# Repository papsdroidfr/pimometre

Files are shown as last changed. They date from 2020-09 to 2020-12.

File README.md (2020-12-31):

# pimometre

Mini station météo de salon connecté équipée d'un capteur de température et d'humidité pour la température ambiante.
Récupération de prévisions météorologiques via une API Rest. 
Les données sont affichées sur un petit écran LCD de 2 lignes de 16 caractères.

Le tutoriel complet du projet est partagé sur mon site: [pimometre](https://www.papsdroid.fr/post/pimometre)

## prototype de test avec capteur et écran LCD

#### choix matériel

* Raspberry pi Zero WH avec Raspbian os lite et WIFI
* 1 capteur température et humidité: DHT22 (précision T°: 0.5°C, précision humidité: 5%)
* 1 résistance 4,7 k ohms
* 1 écran LCD 16*2 avec backpack I2C à base de PCF8574

Pour configurer le piZero: suivez [ce guide](https://www.papsdroid.fr/post/configurer-pizero)

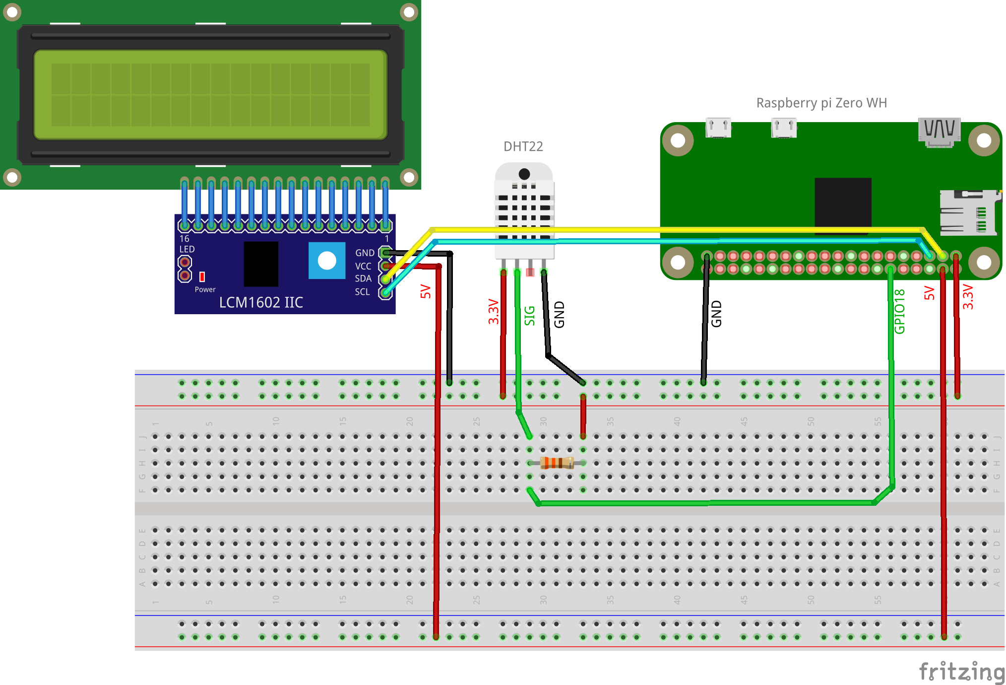
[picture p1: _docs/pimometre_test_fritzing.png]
fritzing_prototype_test


#### test capteur DHT22

Il faut tout d'abord activer l'interface I2C du Raspberry pi avec 
```bach
sudo raspi-config
```
reboot nécessaire.

Pour le capteur DHT22, il faut instaler les dépendances et bilbiothèques circuit-python d'Adafruit en suivant [ce guide](https://circuitpython.readthedocs.io/projects/dht/en/latest/). Pour ce qui me concerne j'ai enchaîné ces commandes:

```bach
sudo pip3 install rpi.GPIO
sudo pip3 install adafruit-blinka
sudo pip3 install adafruit-circuitpython-dht
sudo apt-get install libgpiod2
```

Pour l'afficheur LCD j'ai récupéré la bilbiothèque I2C_LCD_DRIVER.py que je trouve particulièrement bien faite et complète sur [ce site](https://www.circuitbasics.com/raspberry-pi-i2c-lcd-set-up-and-programming/).

Les scripts pythons ci-dessous permettent d'afficher la température et l'humidité ambiante sur le LCD:
* test_LCD_dht22.py
* I2C_LCD_DRIVER.py

Les deux fichiers sont à déposer dans un répertoire /home/pi/pimometre/tests/ du raspberry pi zero.

usage: 
```bach
python3 pimometre/tests/test_LCD_dht22.py
```

#### test API météo

Pour récupérer les prévisions météorologiques locales, il faut d'abord créer un token "standard" sur https://api.meteo-concept.com/

Récupérer votre token, et stockez le dans un fichier texte "tokenAPI.txt", à déposer dans le dossier /home/pimometre/tests, ainsi que le programme python test_meteo_api.py à récupérer parmi les sources.

usage:
```python
cd pimometre/tests
python3 test_meteo_api.py [CP] 
```
en remplaçant [CP] par un code postal dont vous souhaitez les prévisions météo
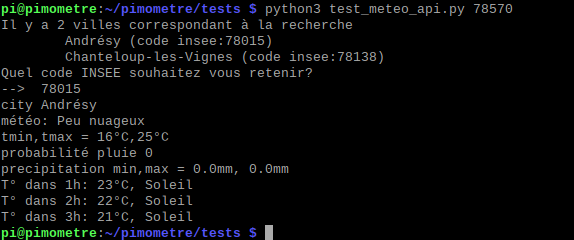
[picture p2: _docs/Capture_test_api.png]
test_api


Pour un même code postal il peut y avoir plusieurs villes: identifiez le code INSEE de la ville pour laquelle vous souhaitez avoir les prévisions météo: ce code sera utilisé pour la suite du projet.

#### première version test du projet: météo interne (capteur) et externe (api).

le programme **pimometre_v1.1.py** dans le répertoire **/tests** permet d'afficher la météo interne capté par le capteur DHT22 (T° et taux d'humidité), ainsi que la température et taux d'humidité exterieure fournie par l'API.

usage: 
```python
cd pimometre/tests
python3 pimometre_v1.1.py [INSEE]
```

remplacer [INSEE] par le code INSEE de votre ville (récupérée via le programme **test_meteo_api.py**) 
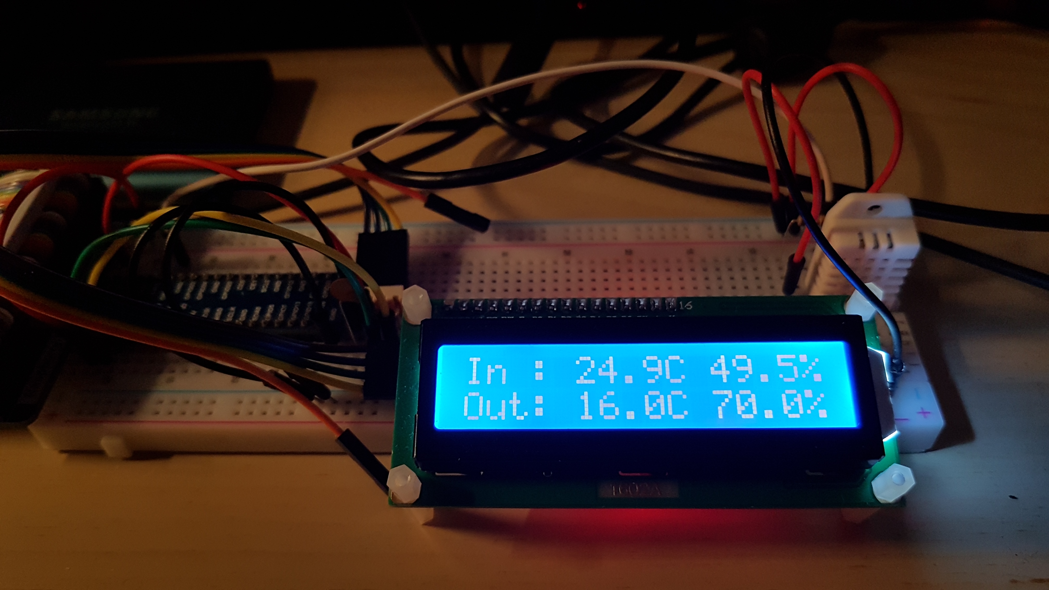
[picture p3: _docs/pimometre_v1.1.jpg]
test_v1.1


Pour pouvoir afficher des informations asynchrones sur un écran (LCD 16*2 en l'occurence), la meilleure solution est de confier la lecture des capteurs à des Threads indépendants. L'application principale consiste à afficher en boucle infinie avec un temps de repos pour ne pas saturer les processeurs ce que les Threads de lecture ont enregistrés la dernière fois qu'ils ont capté quelquechose. Grâce aux Threads On peut ainsi afficher de manière régulière des informations captées par des capteurs qui ne sont absolument pas synchronisés.

Ce programme (orienté objet) contient 3 classes pour gérer l'application:
* Classe **Application**, avec sa boucle principale **loop()** qui affiche en boucle infinie toutes les 2 secondes sur l'écran LCD les lectures faites par le DHT22 et l'appel à l'API météo.
* Classe **DHT22**: capteur interne de T° et humidité. Ce capteur est capricieux et provoque souvent des erreurs de lecture qu'il faut ignorer, et il est conseillé d'attendre au minimum 2 secondes avant de retenter une lecture: un Thread qui lit et enregistre en boucle infinie ce capteur toutes les 2 secondes est particulièrement bien adapté.
* Classe **Meteo**: Thread de lecture de prévision météo via l'api https://api.meteo-concept.com. Ce thread va interroger l'API toutes les 15 mn (60*15 secondes) pour enregistrer la T° et le taux d'humidité de la ville correspondant au code [INSEE] fourni en paramètre lors de l'appel au programme. Attention l'appel à cette API nécessite que vous aillez au préalable **déclaré votre propre token dans le fichier de configuration tokenAPI.txt**

Une seconde version du programme **pimometre_v1.2.py** va permettre de faire défiler plusieurs informations sur la ligne des prévisions météos: température et humidité extérieure, puis vitesse du vent et probabilité de pluie, et enfin le buletin météo qui apparaît en scrolling de la droite vers la gauche.

## projet complet

#### matériel nécessaire

* 1 Raspberry pi Zero WH avec Raspbian os lite et WIFI
* 1 capteur température et humidité: DHT22 (précision T°: 0.5°C, précision humidité: 5%)
* 1 résistance 4,7 k ohms
* 1 écran LCD 16*2 avec backpack I2C à base de PCF8574
* 2 condensateurs céramiques 100nf
* 4 résistances 10 k ohms
* 2 boutons poussoirs 6mm 4 pattes
* 1 jack Barrel DC
* 1 alimentation 5v 2A jack DC
* 1 barette femelle 2*20pin pas 2,54mm pour raspberry pi
* 1 connecteur 4 pin header coudé mâle 2,54mm (pour brancher le LCD)
* 1 connecteur 3 pin header coudé mâle 2,54mm (popur brancher le capteur DHT22)
* des câbles dupond souples femelle/femelle pour racorder le LCD et le DHT22 à la carte
* un jeux d'entretoises nylons M2.5 pour fixer le LCD et surélever le PCB.

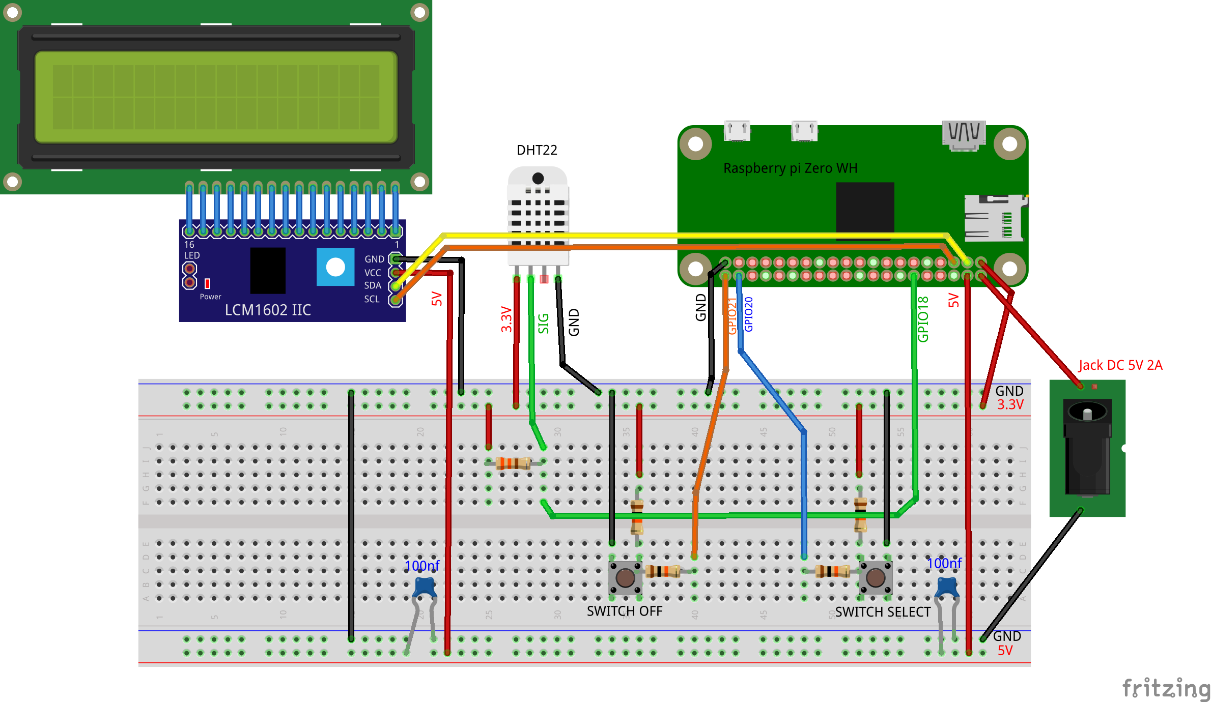
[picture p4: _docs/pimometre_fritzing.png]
fritzing_prototype


#### circuit imprimé

utilisez le fichier zippé **GERBER_pimometre.zip** pour commander le circuit imprimé auprès de n'importe quel fabriquant de PCB.
Vous pourrez y souder tous les composants: les indications claires sont sérigraphiées.
Le raspberry pi se loge par dessous le PCB.
Le LCD et le DHT22 sont connectés à la carte avec des câbles souple femelle/femelle qui se retrouvent entre le circuit imprimé et l'afficheur LCD. 
Il est important de maintenir le capteur DHT22 éloigné du système, pour ne pas que la chaleur dégagée par le raspberry ne perturbe les mesures.

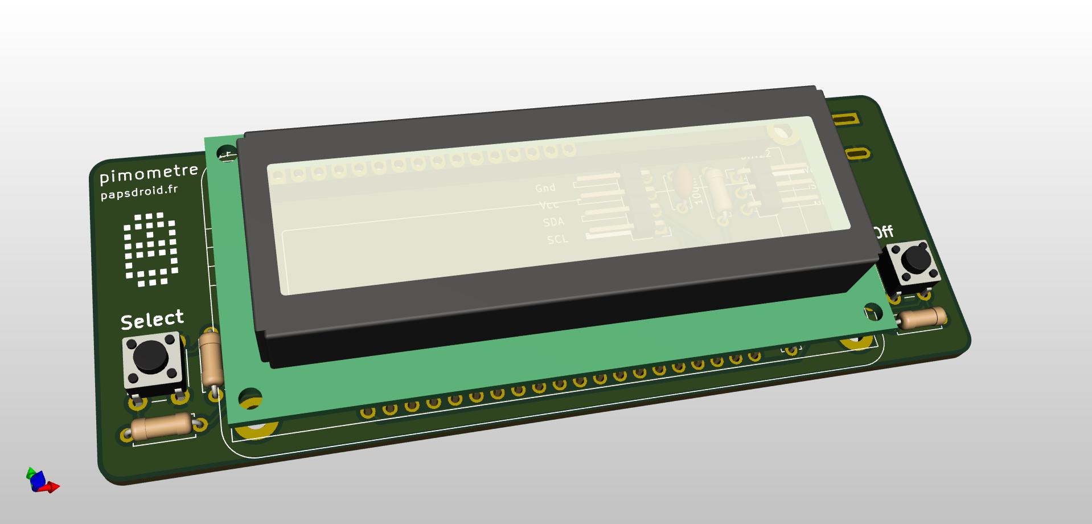
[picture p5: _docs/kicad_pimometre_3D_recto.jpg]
PCB_3D


#### installation du programme python

Dans le répertoire **/home/pi/pimometre** déposer les fichiers **tokenAPI.txt**,  **I2C_LCD_DRIVER.py**, et **pymometre.py** 
Il faut enregistrer son propre token déclaré préalablement dans https://api.meteo-concept.com/ dans le fichier tokenAPI.txt
Installez bien toutes les dépendances comme expliqué dans la partie tests.

Testez d'abord le programme en vous connectant en SSH au piZero:
 
```python
python3 pimometre/pimometre.py [INSEE]
```

remplacer [INSEE] par le code INSEE de votre ville (à ne pas confondre avec le CODE POSTAL ...)

Des messages seront affichés s'il y a des problèmes.

Le script est prévu pour interroger toutes les 5mn l'API météo (cequi génère au maximum 288 appels d'API par jour), et toutes les 10 secondes le capteur DHT22. 
* la première ligne concerne la température et humidité ambiante captée par le DHT22
* la seconde ligne concerne les prévisions météo extérieures via l'API: un premier écran avec la température et l'humidité pendant 2 secondes, puis un second écran avec la vitesse du vent et la probabilité de pluie (2s), un troisième écran avec le bulletin météo en scrolling. La légende à gauche de l'écran indique l'heure de la prévision et une petite icône représentative de ce qui est affiché (thermomètre / soleil / pluie / 5 niveaux de pluie)
* Un appui sur le bouton **Select** va afficher les prévisions météo dans 3h, puis 6h, 9h et retour à l'heure courante
* un appui sur le bouton **Off** va éteindre le système. Pour le redémarrer: il faut enlever et rebrancher le +5v.

#### automatisation au démarrage

Pour que le programme démarre tout seul au démarrage du raspberry pi, il faut ajouter une commande dans la crontable:

ouvrir la crontab en édition
```bach
sudo nano /etc/crontab -e
```

ajouter ces deux lignes à la fin, avant le #:

```python
@reboot pi python3 -u 'pimometre/pimometre.py' [INSEE] > 'pimometre/pimometre.log' 2>&1 &
@daily reboot
```
pensez à remplacer [INSEE] par le code INSEE de votre ville (à ne pas confondre avec le code postal ...)

tappez CTRL-O pour sauvegarder les changements, puis CTRL-X pour quitter

* La première commande indique qu'au démarrage du pizero (@reboot) le user pi doit éxécuter la commande python3 -u .... et rediriger toutes les sorties vers le fichier pimometre/pimometre.log. **Ne pas oublier le & final** qui signifie d'éxécuter la commande en tâche de fond.
* La seconde commande @daily reboot porte bien son nom: elle provoque un reboot automatique du pizero tous les jours (à minuit): quand un système tourne h24 7J/7 avec des logs qui se remplissent, il est conseillé de faire un reboot de temps en temps.Dasn le cas du pimometre la log est assez "verbeuse" donc vaut mieux rebooter toutes les nuit. 

Vous pouvez éteindre le pizero (**sudo poweroff** en SSH), le débrancher quand la lumière verte est éteinte puis le rebrancher.

Lorsqu'il démarre,le programme se lance au bout de quelques instants: **il est normal que la seconde ligne du LCD indique qu'il y a un problème WIFI**: en effet le démarrage des services WIFI est plus lent que l'exécution de la crontable et il faut donc patienter 5mn pour que la deuxième tentative d'appel API (toutes les 5mn) se fasse avec le WIFI activé. Normalement au bout de 5mn le wifi est activé et les prévisions météo de l'heure en cours s'affichent.

Vous pouvez aussi vous connecter en SSH au piZero, et consulter le contenu du fichier de logs dans /home/pi/pimometre/pimometre.log

Le script python est prévu pour gérer les coupures WIFI (par exemple chez moi je coupe le WIFI toutes les nuits de 23h à 07h): les prévisions météos vont alors afficher **"pb cnx API"** et reprendront toutes seules dès que le WIFI est réactivé (à 5mn près).

## Boîtier imprimé 3D

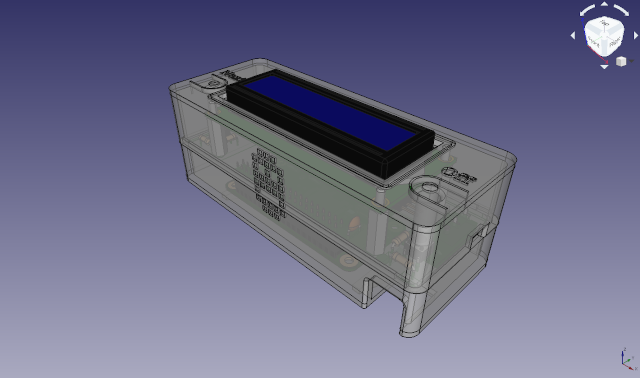
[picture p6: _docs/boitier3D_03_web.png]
pimometre


Un boîtier peut être imprimé en PLA avec une imprimante 3D: télechargez les fichier stl dans le dossier **impression3D** du projet. Ce boîtier peut être imprimé en **0.2mm** (toutes les côtes sont prévues pour) avec les supports uniquement nécessaires pour la coque basse (pour pouvoir imprimer l'ouverture du branchement Jack 5v). Je conseille de cocher l'option **"amélioration de la surface d'adhésion"** car sinon les bords ont tendance à se décoller un peu, ce qui rend la structure du boîtier légèrement bombée et rend difficile (voire impossible) sa fermeture.

Le boîtier peut se poser à plat horizontalement (LCD vers le haut), ou bien inclié à 20° (avec 2 pieds optionnels), ou encore à plat à 90° vissé sur un mur. Il se compose de 3 éléments:
* **coque_basse.stl**: partie basse de la coque dans laquelle se loge la carte. Il faut bien la positionner à raz-bord, elle repose sur les petits rebords. Il faut fixer le LCD avec des petites entretoise nylon M2.5 de **15mm**.
* **coque_haute.stl**: partie haute du boîtier, avec les réhausses de boutons poussoir intégrés. 
* **pied.stl** : à imprimer 2 fois. Ils sont optionnels et ne servent que si vous souhaitez poser le pimomètre incliné à 20°

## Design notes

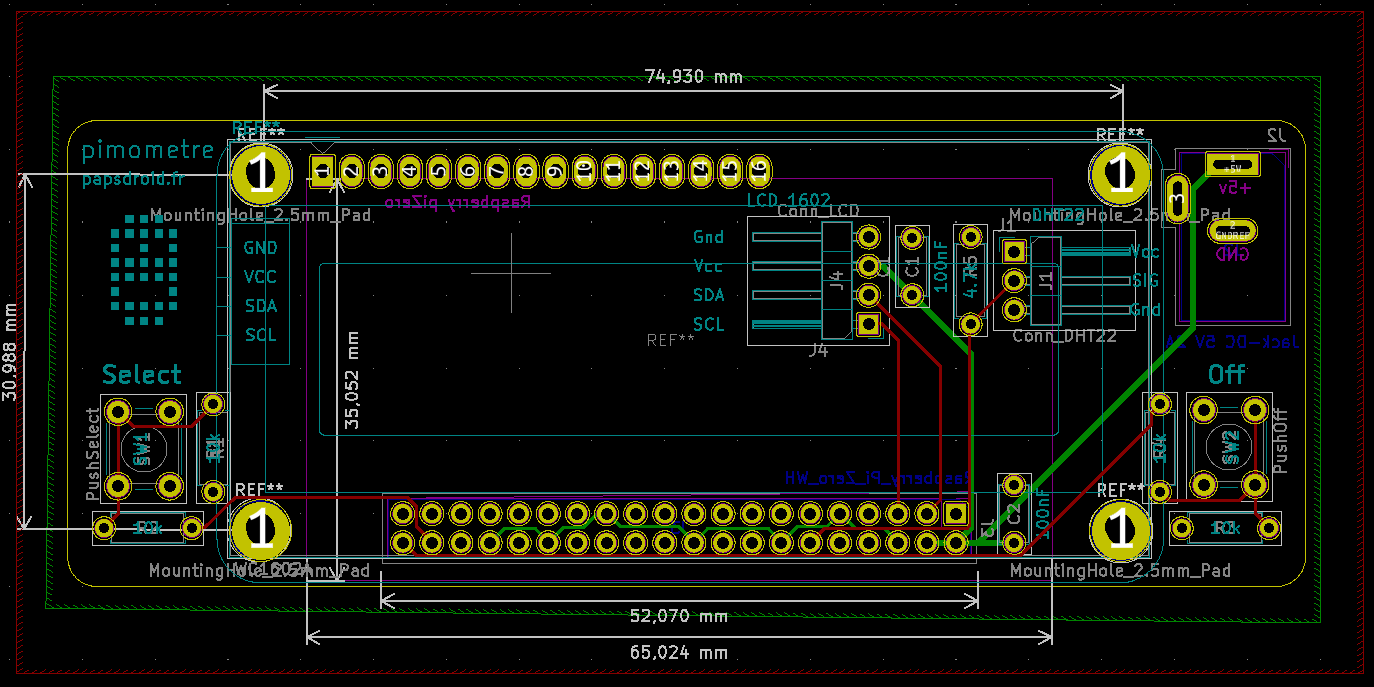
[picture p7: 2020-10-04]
_docs/kicad_pcb.png

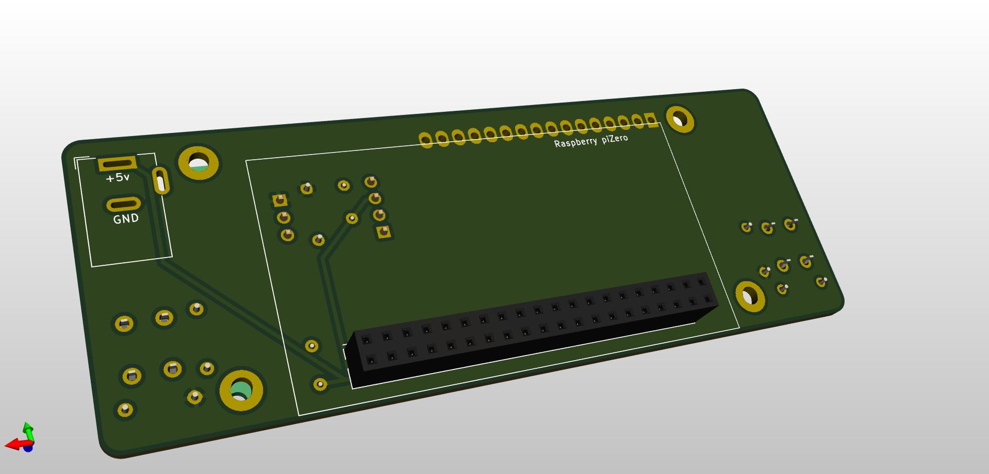
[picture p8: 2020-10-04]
_docs/kicad_pimometre_3D_verso.jpg

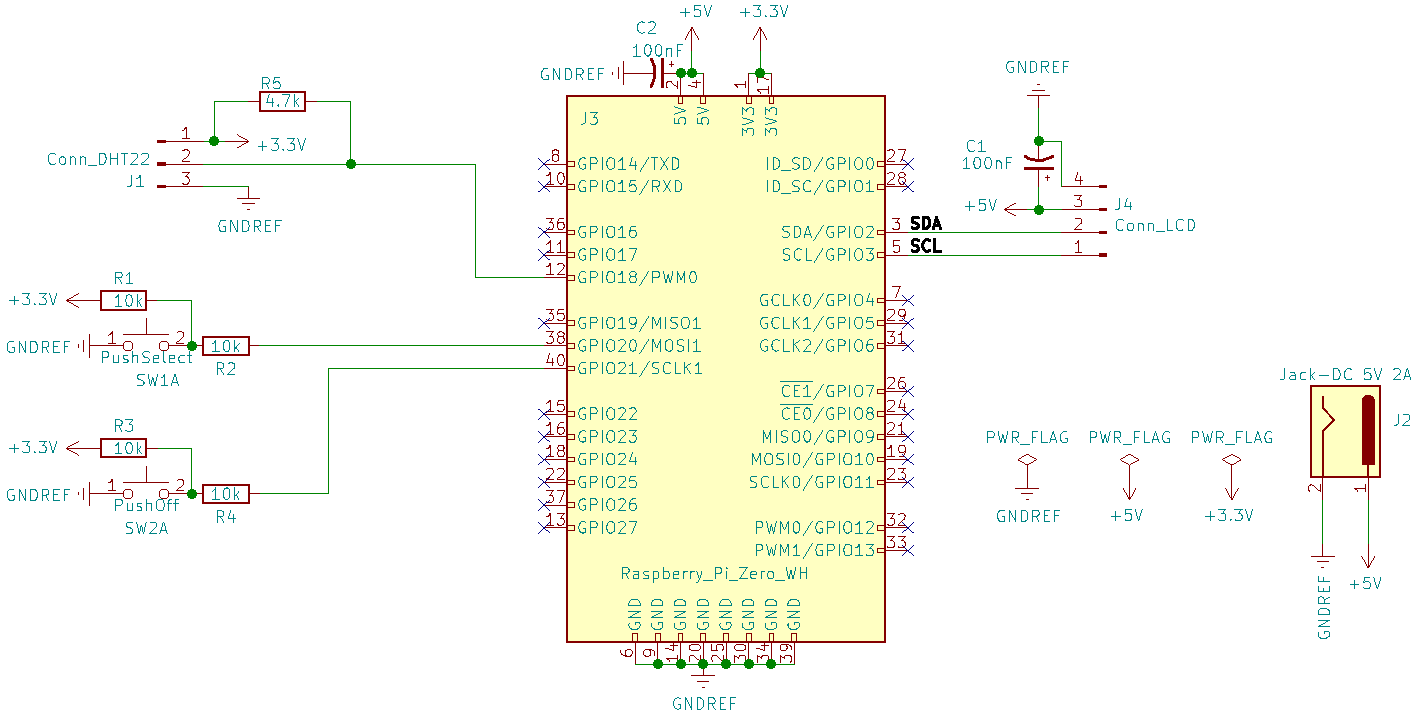
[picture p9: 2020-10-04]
_docs/Kicad_schema.png

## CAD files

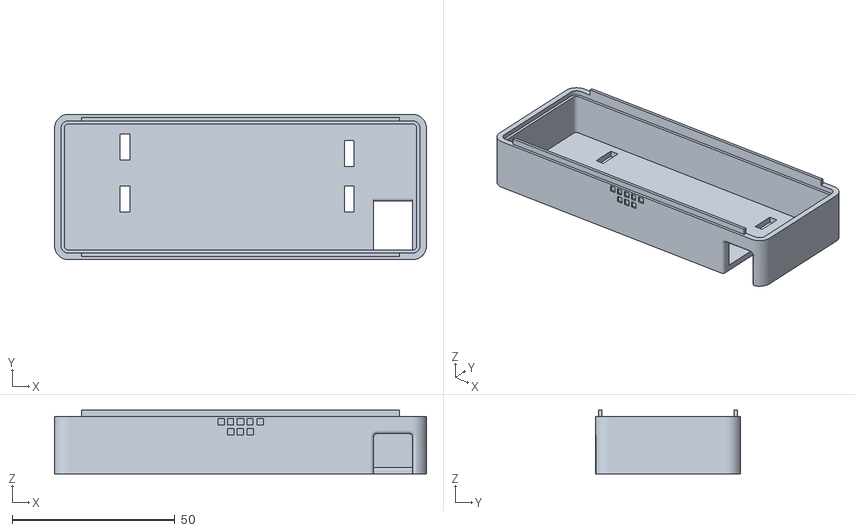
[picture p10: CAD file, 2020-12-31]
impression3D/coque_basse.stl
114.4 x 44.7 x 19.6

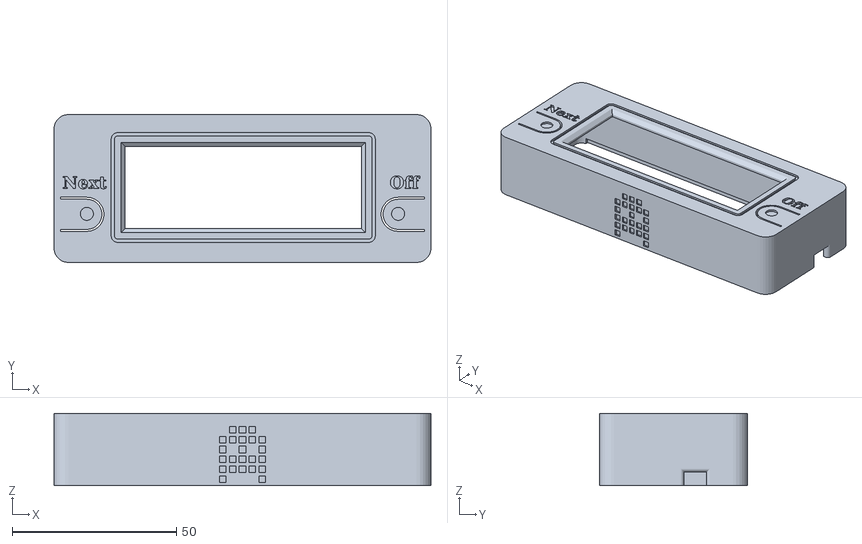
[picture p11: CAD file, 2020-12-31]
impression3D/coque_haute.stl
114.8 x 45.0 x 22.0

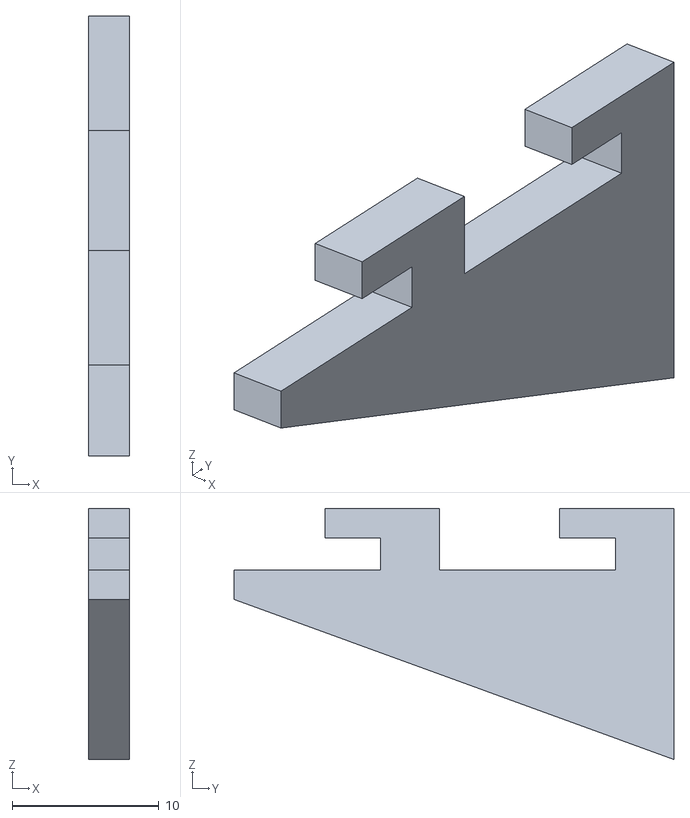
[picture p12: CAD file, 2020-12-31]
impression3D/pied.stl
2.80 x 30.0 x 17.1

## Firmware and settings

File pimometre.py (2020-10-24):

#!/usr/bin/env python3
# -*- coding: utf-8 -*-
########################################################################
# Filename    : pimometre.py
# Description : station météo de salon avec prévision
# auther      : papsdroid.fr
# creation    : 2020/09/20
# modification: 2020/10/24
########################################################################

import RPi.GPIO as GPIO
import time, board,os, adafruit_dht,threading,  I2C_LCD_DRIVER
from datetime import datetime
from contextlib import closing
from urllib.request import urlopen
from urllib.error import URLError
import json, sys, unicodedata


class DHT22(threading.Thread):
    """ classe capteur de t° et humidité DHT22"""
    def __init__(self):
        """ constructeur """
        threading.Thread.__init__(self)  # appel au constructeur de la classe mère Thread
        print("Init capteur DHT22")
        self.dhtDevice = adafruit_dht.DHT22(board.D18) # catpeur T°  humidity DHT22
        self.delay = 10                  # delay in s before reading a new mesure
        self.temperature_c = None
        self.humidity = None
        self.readOk   = False            # True: lecture capteur ok
        self.start()                     # start thread

    def run(self):
        """ exécution thread: lit T° et humidité du capteur DHT22 toutes les sefl.delay secondes
            valeurs stockées dans self.temperature_c et self.humidity
        """
        self.etat = True
        while self.etat:
            try:
                self.temperature_c = self.dhtDevice.temperature
                self.humidity = self.dhtDevice.humidity
                self.readOk = True
            except :
                self.readOk = False
                print(datetime.now(),' DHT22 read Error')
            time.sleep(self.delay) #wait at least 2s before reading a new mesure
        self.off()  # free dht22 device

    def off(self):
        """ arrêt thread de lecture T° DHT22 """
        print("DHT22 exit")
        self.dhtDevice.exit()

class Meteo(threading.Thread):
    """ recup données API meto https://api.meteo-concept.com/ 
        thread de prevision météo mis à jour toutes les self.delay secondes 
    """
    def __init__(self, insee=None):
        """ constructeur """
        threading.Thread.__init__(self)  # appel au constructeur de la classe mère Thread
        self.delay = 60*5                # délais attente avant nouvelle interrogation API
        self.delay_retry = 5             # délais retentative appel API en cas de pb (exple WIFI KO)
        self.insee = insee               # code INSEE de la ville pour les prévisions
        self.forecast = None             # prévisions météo (API)
        self.apiOK = False               # passe à True si thread démarré et réponse API OK
        #-- get token from tokenAPI.txt file
        try:
            with open('tokenAPI.txt','r') as f:
                self.mytoken= f.read().strip('\n')
                print('token="' + self.mytoken + '"')
        except:
            print('Créer un fichier tokenAPI.txt avec le token en 1ere ligne')
            self.mytoken = None

        #--dic weather code
        self.WEATHER = {
            0: "Soleil",
            1: "Peu nuageux",
            2: "Ciel voilé",
            3: "Nuageux",
            4: "Très nuageux",
            5: "Couvert",
            6: "Brouillard",
            7: "Brouillard givrant",
            10: "Pluie faible",
            11: "Pluie modérée",
            12: "Pluie forte",
            13: "Pluie faible verglaçante",
            14: "Pluie modérée verglaçante",
            15: "Pluie forte verglaçante",
            16: "Bruine",
            20: "Neige faible",
            21: "Neige modérée",
            22: "Neige forte",
            30: "Pluie et neige mêlées faibles",
            31: "Pluie et neige mêlées modérées",
            32: "Pluie et neige mêlées fortes",
            40: "Averses de pluie locales et faibles",
            41: "Averses de pluie locales",
            42: "Averses locales et fortes",
            43: "Averses de pluie faibles",
            44: "Averses de pluie",
            45: "Averses de pluie fortes",
            46: "Averses de pluie faibles et fréquentes",
            47: "Averses de pluie fréquentes",
            48: "Averses de pluie fortes et fréquentes",
            60: "Averses de neige localisées et faibles",
            61: "Averses de neige localisées",
            62: "Averses de neige localisées et fortes",
            63: "Averses de neige faibles",
            64: "Averses de neige",
            65: "Averses de neige fortes",
            66: "Averses de neige faibles et fréquentes",
            67: "Averses de neige fréquentes",
            68: "Averses de neige fortes et fréquentes",
            70: "Averses de pluie et neige mêlées localisées et faibles",
            71: "Averses de pluie et neige mêlées localisées",
            72: "Averses de pluie et neige mêlées localisées et fortes",
            73: "Averses de pluie et neige mêlées faibles",
            74: "Averses de pluie et neige mêlées",
            75: "Averses de pluie et neige mêlées fortes",
            76: "Averses de pluie et neige mêlées faibles et nombreuses",
            77: "Averses de pluie et neige mêlées fréquentes",
            78: "Averses de pluie et neige mêlées fortes et fréquentes",
            100: "Orages faibles et locaux",
            101: "Orages locaux",
            102: "Orages fort et locaux",
            103: "Orages faibles",
            104: "Orages",
            105: "Orages forts",
            106: "Orages faibles et fréquents",
            107: "Orages fréquents",
            108: "Orages forts et fréquents",
            120: "Orages faibles et locaux de neige ou grésil",
            121: "Orages locaux de neige ou grésil",
            122: "Orages locaux de neige ou grésil",
            123: "Orages faibles de neige ou grésil",
            124: "Orages de neige ou grésil",
            125: "Orages de neige ou grésil",
            126: "Orages faibles et fréquents de neige ou grésil",
            127: "Orages fréquents de neige ou grésil",
            128: "Orages fréquents de neige ou grésil",
            130: "Orages faibles et locaux de pluie et neige mêlées ou grésil",
            131: "Orages locaux de pluie et neige mêlées ou grésil",
            132: "Orages fort et locaux de pluie et neige mêlées ou grésil",
            133: "Orages faibles de pluie et neige mêlées ou grésil",
            134: "Orages de pluie et neige mêlées ou grésil",
            135: "Orages forts de pluie et neige mêlées ou grésil",
            136: "Orages faibles et fréquents de pluie et neige mêlées ou grésil",
            137: "Orages fréquents de pluie et neige mêlées ou grésil",
            138: "Orages forts et fréquents de pluie et neige mêlées ou grésil",
            140: "Pluies orageuses",
            141: "Pluie et neige mêlées à caractère orageux",
            142: "Neige à caractère orageux",
            210: "Pluie faible intermittente",
            211: "Pluie modérée intermittente",
            212: "Pluie forte intermittente",
            220: "Neige faible intermittente",
            221: "Neige modérée intermittente",
            222: "Neige forte intermittente",
            230: "Pluie et neige mêlées",
            231: "Pluie et neige mêlées",
            232: "Pluie et neige mêlées",
            235: "Averses de grêle",
            }

        self.URLAPI   = 'https://api.meteo-concept.com/api'
        self.GETHOURS = '/forecast/nextHours'
        self.HOURLY   = '&hourly=true' #GET forecast every  hour
        if (self.mytoken is not None and self.insee is not None):
            self.TOKEN  = '?token='+self.mytoken
            self.SEARCH = '&insee='+self.insee
            self.start() # start thread

    def run(self):
        """ thread start """
        self.etat = True
        while self.etat:
            try:
                with closing(urlopen(self.URLAPI+self.GETHOURS+self.TOKEN+self.HOURLY+self.SEARCH)) as f:
                    decoded = json.loads(f.read())
                    self.forecast = decoded['forecast']
                    self.city = decoded['city']['name']
                    print('{}: mise à jour prévisions météo de {} à {} (nb:{}) {}'.format(datetime.now(),self.forecast[0]['datetime'],
                               self.city, len(self.forecast), self.WEATHER[self.forecast[0]['weather']]))
                    self.apiOK = True
                    time.sleep(self.delay)
            except URLError as error: # HTTPError(req.full_url, code, msg, hdrs, fp)
                if not(self.apiOK) or self.forecast is not None:
                    print(datetime.now(),':pb connexion API, vérifier le token ou la connexion WIFI:',error)
                    self.forecast = None
                time.sleep(self.delay_retry)  # nouvelle tentative toute les self.delay_retry secondes

class LCD:
    """ classe gestion du LCD """
    def __init__(self):
        """ constructeur """
        self.lcd =  I2C_LCD_DRIVER.lcd()        # LCD 16*2
        self.lcd.backlight(1)                   # turn LCD backligth on
        fontdata = [ [0b00100,0b01010,0b01010,0b01010,0b11011,0b10111,0b11111,0b01110], #0 = thermometre
                     [0b00000,0b00100,0b11110,0b11111,0b01010,0b01001,0b00100,0b00000], #1 = clouds rain
                     [0b10101,0b01110,0b10001,0b10001,0b10001,0b01110,0b10101,0b00000], #2 = sun
                     [0b00000,0b01110,0b10001,0b10001,0b10001,0b11111,0b11111,0b00000], #3 level     [0-25[   %
                     [0b00000,0b01110,0b10001,0b10001,0b11111,0b11111,0b11111,0b0000] , #4 level [25-50[  %
                     [0b00000,0b01110,0b10001,0b11111,0b11111,0b11111,0b11111,0b00000], #5 level [50-75[  %
                     [0b00000,0b01110,0b11101,0b11111,0b11111,0b11111,0b11111,0b00000], #6 level [75-100[ %
                     [0b00000,0b01110,0b11111,0b11111,0b11111,0b11111,0b11111,0b00000], #7 level 100 %
                   ]
        self.lcd.lcd_load_custom_chars(fontdata)

    def off(self):
        """ extinction LCD """
        self.lcd.lcd_clear()     # clear LCD 
        self.lcd.backlight(0)    # turn LCD backligth off

    def display_string(self, s, lig=1, col=0):
        """ display string s at (lig,col) """
        self.lcd.lcd_display_string(s, lig, col)

    def display_char(self, n, lig=1, col=0):
        """ display special char(n) loaded from fontdata at (lig,col) """
        if lig==1:
            self.lcd.lcd_write(0x80+col)  # position lig1 @col
        else:
            self.lcd.lcd_write(0xC0+col)  # position lig2 @col
        self.lcd.lcd_write_char(n)

    def display_level(self, level, lig=1, col=0):
        """ display level char loaded from fontdata at (lig,col) """
        self.display_char(3 + level//25, lig, col)

    def scroll_string(self, s, lig=1, col=0):
        """ scroll string s rigth to left at (lig, col) """
        padding = " " * (16-col)
        padded_s = padding + s
        for i in range(len(padded_s)):
            lcd_text = padded_s[i:(i+16-col)]
            self.lcd.lcd_display_string(lcd_text, lig, col)
            time.sleep(0.3)
            self.lcd.lcd_display_string(padding, lig,col)

class Application:
    """ classe d'application principale """
    def __init__(self):
        print("démarrage pimometre")
        self.dht22 = DHT22()                    # dht22 device (thread)
        self.meteo = Meteo(insee=sys.argv[1])   # meteo API (thread)
        self.lcd = LCD()                        # LCD 16*2
        self.idforecast=0                       # n° de prévision météo séléctionnée
        self.on = True                          # affichage en boucle si True
        self.next = False                       # affichage suivant si True
        self.buttonSelectPin = 20               # bouton SELECT pour changer l'affichage
        self.buttonOffPin = 21                  # bouton OFF d'extinction
        #pin associés aux boutons poussoirs
        GPIO.setup(self.buttonSelectPin, GPIO.IN, pull_up_down=GPIO.PUD_UP)     # mode INPUT, pull_up=high
        GPIO.setup(self.buttonOffPin, GPIO.IN, pull_up_down=GPIO.PUD_UP)        # mode INPUT, pull_up=high
        GPIO.add_event_detect(self.buttonSelectPin,GPIO.FALLING,callback = self.buttonSelectEvent, bouncetime=300)
        GPIO.add_event_detect(self.buttonOffPin,GPIO.FALLING,callback=self.buttonOffEvent, bouncetime=300)

    def buttonOffEvent(self, hcannel):
        """ méthode exécutée lors d'un appuie sur le bouton Off """
        print(datetime.now(), 'Bouton Off préssé')
        self.destroy()         # arrêt des threads et extinction du LCD
        time.sleep(2)
        os.system('sudo halt') # provoque l'extinction du Raspberry pi

    def buttonSelectEvent(self, channel):
        """ méthode exécutée lors d'un appui sur le bonton SELECT """
        self.next=True
        self.idforecast += 3   # prévisions à +3h
        if self.idforecast == len(self.meteo.forecast):
            self.idforecast = 0
        print('--> SELECT prévisions météo à {}'.format(self.meteo.forecast[self.idforecast]['datetime']))

    def destroy(self):
        """ quitter l'appli"""
         #-- stop threads
        self.on = False             #arrêt boucle principale application
        self.dht22.etat = False
        self.meteo.etat = False
        print(datetime.now(),'bye')
        self.lcd.off()     # clear LCD

    def loop(self):
        """ boucle principale de l'appli """
        self.lcd.display_string('In  init dht22..',1)
        self.lcd.display_string('Ex  init API ...',2)
        self.lcd.display_char(0,1,3) # thermometre symbol
        self.lcd.display_char(0,2,3) # thermometre symbol

        while self.on:

            #temperature  intérieure
            if (self.dht22.temperature_c is not None and self.dht22.humidity is not None):
                #legende
                if self.dht22.readOk:
                    self.lcd.display_string('In ',1)
                else:
                    self.lcd.display_string('In*',1) #une étoile est ajoutée si la dernière mesure n'a pas abouti
                #température et humidité
                self.lcd.display_string("{:00.1f}{}C {:00.1f}%".format(self.dht22.temperature_c,chr(223),self.dht22.humidity),1,4)

            # méteo extérieure via API
            if self.meteo.forecast is not None:
                #legende
                try:  # carefully use of self.meteo.forecast that can turn into None at any time (Thread).
                    t = self.meteo.forecast[self.idforecast]['datetime']
                    self.lcd.display_string(t[11:13]+'h',2) # heure de prédiction HH
                except:
                    continue

                #température
                try:
                    self.lcd.display_char(0,2,3) # thermometre symbol
                    self.lcd.display_string("{:.1f}{}C {:.1f}%".format(self.meteo.forecast[self.idforecast]['temp2m'], chr(223),
                                                                          self.meteo.forecast[self.idforecast]['rh2m']), 2,4)
                    if self.on and not(self.next):
                        time.sleep(2)
                except:
                    continue

                # wind, proba rain
                if self.on and not(self.next):
                    try:
                        probarain = self.meteo.forecast[self.idforecast]['probarain']
                        self.lcd.display_level(probarain,2,3)  # level symbol based on proba rain
                        self.lcd.display_string(" "*12,2,4)
                        self.lcd.display_string("{:.0f}km/h {:.1f}%".format(self.meteo.forecast[self.idforecast]['wind10m'],probarain),2,4)
                        time.sleep(2)
                    except:
                        continue

                # scroll meteo long string
                if self.on and not(self.next):
                    try:
                        weather = self.meteo.forecast[self.idforecast]['weather']
                        if  weather < 10: # sun
                            self.lcd.display_char(2,2,3) # sun symbol
                        else:
                            self.lcd.display_char(1,2,3) # rain & clouds symbol
                        s = self.meteo.WEATHER[weather]  # label correspondant au code météo
                        s = unicodedata.normalize('NFKD', s).encode('ASCII', 'ignore').decode('utf-8')  # supprime tous les accents
                        self.lcd.scroll_string(s,2,4)
                    except:
                        continue

                if self.on and self.next:
                    self.next=False

            else:
                self.lcd.display_string(' pb cnx API ',2,4)
                if self.on:
                    time.sleep(2) # délais de rafraichissement écran LCD

if __name__ == '__main__':
    if len(sys.argv) == 1 :
        print("Iniquez un code INSEE --> usage: python3 pimometre.py [INSEE]")
        exit(0)
    appl=Application()
    try:
        appl.loop()
    except KeyboardInterrupt:  # interruption clavier CTRL-C: appel à la méthode destroy() de appl.
        appl.destroy()

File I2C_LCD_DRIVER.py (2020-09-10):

# -*- coding: utf-8 -*-
# Original code found at:
# https://gist.github.com/DenisFromHR/cc863375a6e19dce359d

"""
Compiled, mashed and generally mutilated 2014-2015 by Denis Pleic
Made available under GNU GENERAL PUBLIC LICENSE

# Modified Python I2C library for Raspberry Pi
# as found on http://www.recantha.co.uk/blog/?p=4849
# Joined existing 'i2c_lib.py' and 'lcddriver.py' into a single library
# added bits and pieces from various sources
# By DenisFromHR (Denis Pleic)
# 2015-02-10, ver 0.1

"""

# i2c bus (0 -- original Pi, 1 -- Rev 2 Pi)
I2CBUS = 1

# LCD Address
ADDRESS = 0x27

import smbus
from time import sleep

class i2c_device:
   def __init__(self, addr, port=I2CBUS):
      self.addr = addr
      self.bus = smbus.SMBus(port)

# Write a single command
   def write_cmd(self, cmd):
      self.bus.write_byte(self.addr, cmd)
      sleep(0.0001)

# Write a command and argument
   def write_cmd_arg(self, cmd, data):
      self.bus.write_byte_data(self.addr, cmd, data)
      sleep(0.0001)

# Write a block of data
   def write_block_data(self, cmd, data):
      self.bus.write_block_data(self.addr, cmd, data)
      sleep(0.0001)

# Read a single byte
   def read(self):
      return self.bus.read_byte(self.addr)

# Read
   def read_data(self, cmd):
      return self.bus.read_byte_data(self.addr, cmd)

# Read a block of data
   def read_block_data(self, cmd):
      return self.bus.read_block_data(self.addr, cmd)


# commands
LCD_CLEARDISPLAY = 0x01
LCD_RETURNHOME = 0x02
LCD_ENTRYMODESET = 0x04
LCD_DISPLAYCONTROL = 0x08
LCD_CURSORSHIFT = 0x10
LCD_FUNCTIONSET = 0x20
LCD_SETCGRAMADDR = 0x40
LCD_SETDDRAMADDR = 0x80

# flags for display entry mode
LCD_ENTRYRIGHT = 0x00
LCD_ENTRYLEFT = 0x02
LCD_ENTRYSHIFTINCREMENT = 0x01
LCD_ENTRYSHIFTDECREMENT = 0x00

# flags for display on/off control
LCD_DISPLAYON = 0x04
LCD_DISPLAYOFF = 0x00
LCD_CURSORON = 0x02
LCD_CURSOROFF = 0x00
LCD_BLINKON = 0x01
LCD_BLINKOFF = 0x00

# flags for display/cursor shift
LCD_DISPLAYMOVE = 0x08
LCD_CURSORMOVE = 0x00
LCD_MOVERIGHT = 0x04
LCD_MOVELEFT = 0x00

# flags for function set
LCD_8BITMODE = 0x10
LCD_4BITMODE = 0x00
LCD_2LINE = 0x08
LCD_1LINE = 0x00
LCD_5x10DOTS = 0x04
LCD_5x8DOTS = 0x00

# flags for backlight control
LCD_BACKLIGHT = 0x08
LCD_NOBACKLIGHT = 0x00

En = 0b00000100 # Enable bit
Rw = 0b00000010 # Read/Write bit
Rs = 0b00000001 # Register select bit

class lcd:
   #initializes objects and lcd
   def __init__(self):
      self.lcd_device = i2c_device(ADDRESS)

      self.lcd_write(0x03)
      self.lcd_write(0x03)
      self.lcd_write(0x03)
      self.lcd_write(0x02)

      self.lcd_write(LCD_FUNCTIONSET | LCD_2LINE | LCD_5x8DOTS | LCD_4BITMODE)
      self.lcd_write(LCD_DISPLAYCONTROL | LCD_DISPLAYON)
      self.lcd_write(LCD_CLEARDISPLAY)
      self.lcd_write(LCD_ENTRYMODESET | LCD_ENTRYLEFT)
      sleep(0.2)


   # clocks EN to latch command
   def lcd_strobe(self, data):
      self.lcd_device.write_cmd(data | En | LCD_BACKLIGHT)
      sleep(.0005)
      self.lcd_device.write_cmd(((data & ~En) | LCD_BACKLIGHT))
      sleep(.0001)

   def lcd_write_four_bits(self, data):
      self.lcd_device.write_cmd(data | LCD_BACKLIGHT)
      self.lcd_strobe(data)

   # write a command to lcd
   def lcd_write(self, cmd, mode=0):
      self.lcd_write_four_bits(mode | (cmd & 0xF0))
      self.lcd_write_four_bits(mode | ((cmd << 4) & 0xF0))

   # write a character to lcd (or character rom) 0x09: backlight | RS=DR<
   # works!
   def lcd_write_char(self, charvalue, mode=1):
      self.lcd_write_four_bits(mode | (charvalue & 0xF0))
      self.lcd_write_four_bits(mode | ((charvalue << 4) & 0xF0))
  
   # put string function with optional char positioning
   def lcd_display_string(self, string, line=1, pos=0):
    if line == 1:
      pos_new = pos
    elif line == 2:
      pos_new = 0x40 + pos
    elif line == 3:
      pos_new = 0x14 + pos
    elif line == 4:
      pos_new = 0x54 + pos

    self.lcd_write(0x80 + pos_new)

    for char in string:
      self.lcd_write(ord(char), Rs)

   # clear lcd and set to home
   def lcd_clear(self):
      self.lcd_write(LCD_CLEARDISPLAY)
      self.lcd_write(LCD_RETURNHOME)

   # define backlight on/off (lcd.backlight(1); off= lcd.backlight(0)
   def backlight(self, state): # for state, 1 = on, 0 = off
      if state == 1:
         self.lcd_device.write_cmd(LCD_BACKLIGHT)
      elif state == 0:
         self.lcd_device.write_cmd(LCD_NOBACKLIGHT)

   # add custom characters (0 - 7)
   def lcd_load_custom_chars(self, fontdata):
      self.lcd_write(0x40);
      for char in fontdata:
         for line in char:
            self.lcd_write_char(line)     

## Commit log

2020-10-04 Add files via upload
    Fichiers Gerber (zipés) pour fabrication du PCB
2020-10-04 Add files via upload
    Fichier dans lequel il faut écrire son token déclaré dans https://api.meteo-concept.com/
2020-10-04 Add files via upload
    I2C LCD driver
